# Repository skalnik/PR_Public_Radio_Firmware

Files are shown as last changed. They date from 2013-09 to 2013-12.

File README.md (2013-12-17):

PR_Public_Radio README
===============
Created 2013.12.17
by Spencer Wright
===============
SYNOPSIS
The Public Radio is a project which spans industrial design, embedded systems design, and firmware.The files located within this project comprise a subset of the data reqired to fully complete ThePublic Radio, though efforts are being made to completely describe the project from top to bottom.
===============
CREDITS
The work herein is primarily a collaboration between Spencer Wright (http://pencerw.com) and Zach Dunham (http://zachdunham.com) though much ofit was adapted heavily from friendly sources. In particular, early versions of the firmware was adapted directly from Nathan Seidle et al (Sparkfun). Special thanks also goes to Todd Bailey (http://blog.narrat1ve.com/).
===============
LICENSE
In the interest of collaboration and good will, the files herein are offered for public use. Just don't be a jerk about it, etc., and do let us know if we've screwed something really big up (and, of course, we certainly have :).
At some point in the future, The Public Radio will be made commercially available. Inasmuch as it is feasible, we hope to continue to keep the design files and firmware here available for noncommercial use.
===============
PROJECT DESCRIPTION
The Public Radio is a single channel, single speaker FM receiver. 
As a piece of hardware, it was intended to be as simple as possible. One midrange speaker mounted inside a simple enclosure, with a single switched knob which controls power and adjusts volume.
Early on in the project, we planned on building a custom aluminum enclosure, but decided to protoype using an off-the-shelf container - a Ball brand mason jar. The enclosure requires one custom manufactured part: a replacement lid, to which the speaker, potentiometer, and electronics mount.
As I write this, the electronics consist primarily of off-the-shelf components: Arduino Pro Mini, Sparkfun breakout & evaluation boards. Our plan for the next few months includes stripping the hardware down to its barest components and discarding the prototyping tools we've used to get ourselves off the ground.
The firmware required to run The Public Radio is simple. The main Arduino sketch does the following:
  Defines three output pins
  Defines "channel" (FM frequency) and "volume" variables
  Instantiates the class Public_Radio
  Enables the Si4703 FM receiver chip
  Tunes to the defined frequency 
  Sets the volume
Also included are stripped down versions of the Si4703 written by Sparkfun and available at https://github.com/sparkfun/Si4703_FM_Tuner_Evaluation_Board. As my understanding of these is limited, I'll reserve description until a later date.
===============
CONTAINED HEREIN
  Industrial design files: These are mostly outdated, and were created in SolidWorks. Current versions, created primarily in Autodesk Inventor, still need to be folded into this repo.
  Embedded systems design files: Namely .brd, .sch, possibly gerbers. These will remain up-to-date, so long as I can keep ZD on his game :)
  Firmware: Arduino sketches, library files (header & source). 
===============
ELSE
I'm new to this game. Holler at me if I'm missing something.

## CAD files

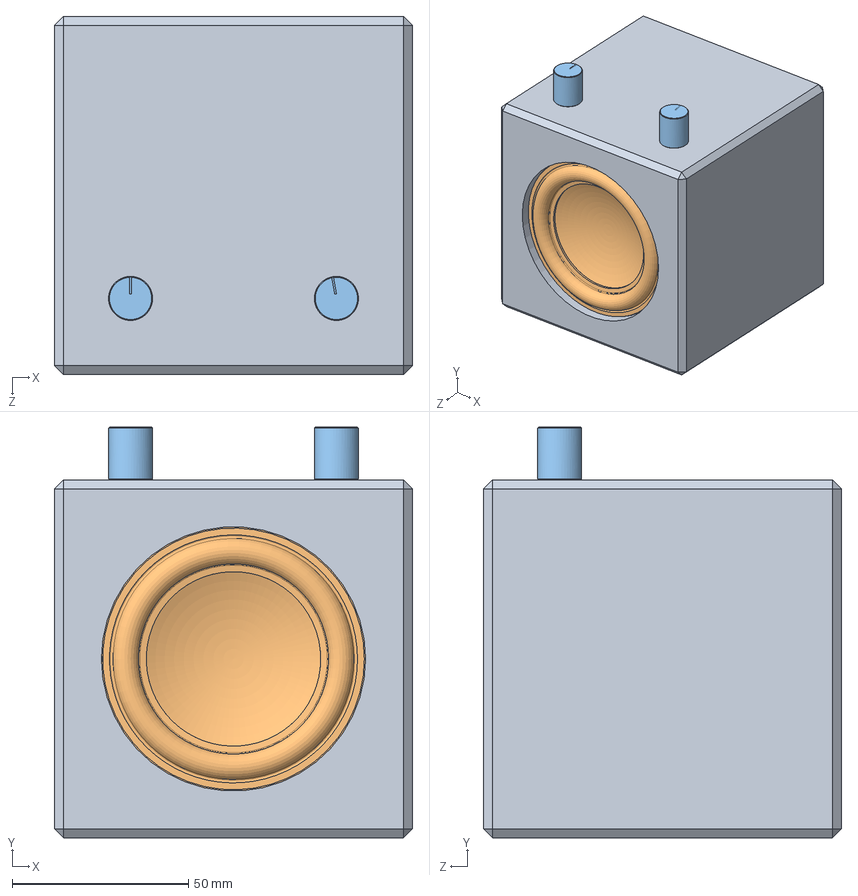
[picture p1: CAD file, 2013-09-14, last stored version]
APR1001 Public Radio.SLDASM
101.6 x 116.6 x 101.6 mm
PR1001 Speaker box
PR2001 Speaker Swan B3S
PR1002 Knob x 2

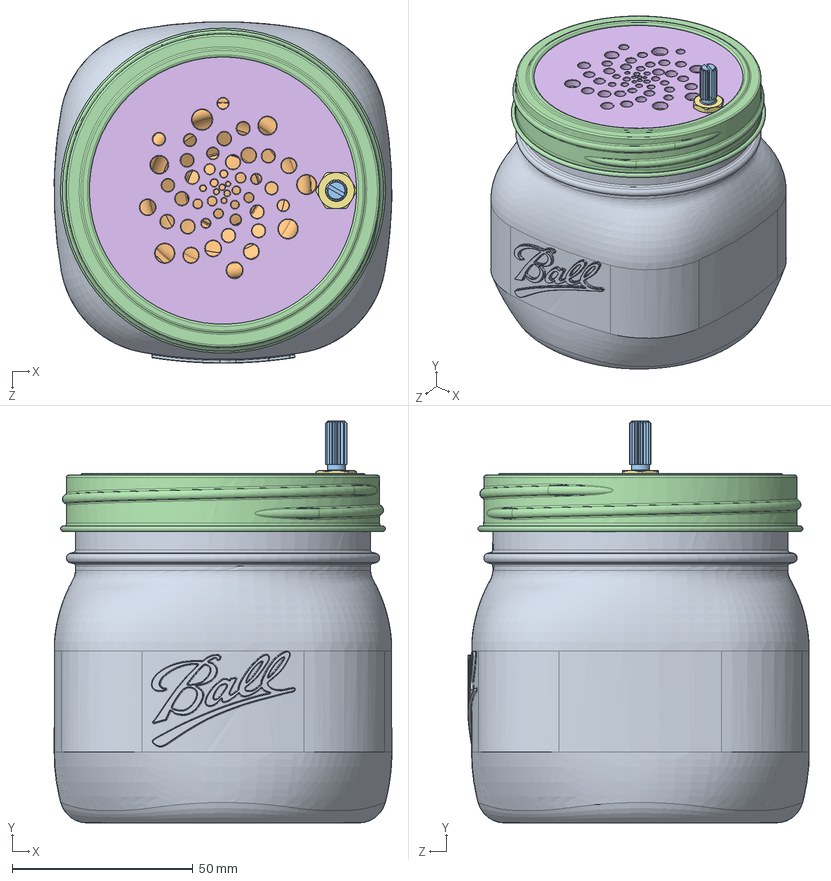
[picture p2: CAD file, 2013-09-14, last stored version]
PR_Solidworks/APR1002 Ball Public Radio.SLDASM
93.4 x 111.2 x 94.5 mm
PR2003 Ball Jar 500mL squareish
PR2004 Speaker Viifa TC6FC00-04
PR2005 Potentiometer Bourns BTR901-2015K-A103
PR2006 Ball Wide Mouth Ring
PR2007 9 Volt Battery
PR1005 Fibonacci Lid 2
PR2008 Bourns locknut

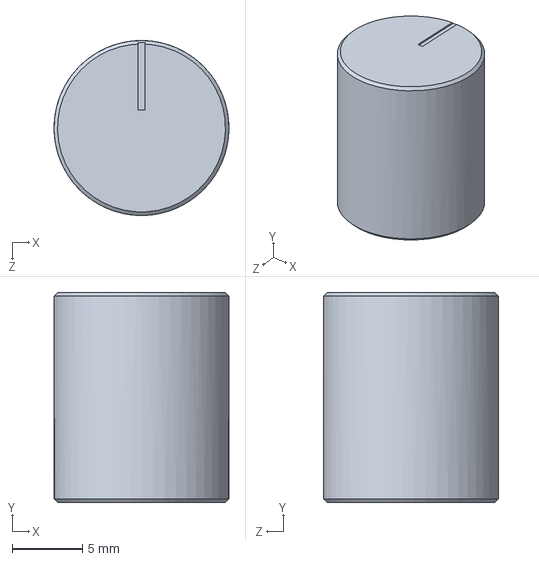
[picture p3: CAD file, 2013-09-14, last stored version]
PR1002 Knob.SLDPRT
12.5 x 15.0 x 12.5 mm

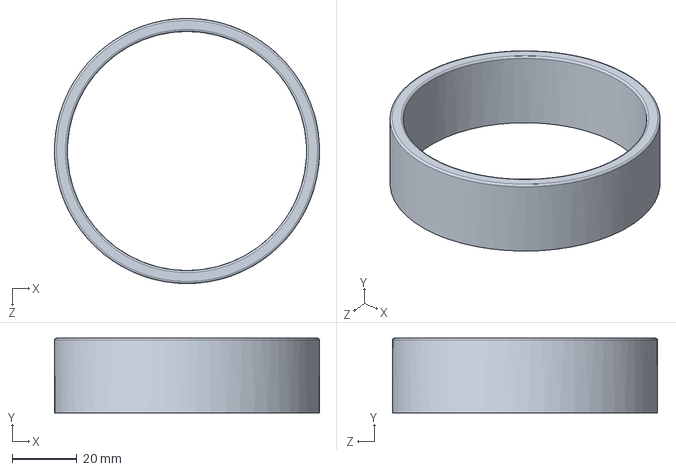
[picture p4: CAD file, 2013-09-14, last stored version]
PR_Solidworks/PR2003 Ball Jar 1qt squareish.SLDPRT
81.8 x 23.1 x 81.8 mm

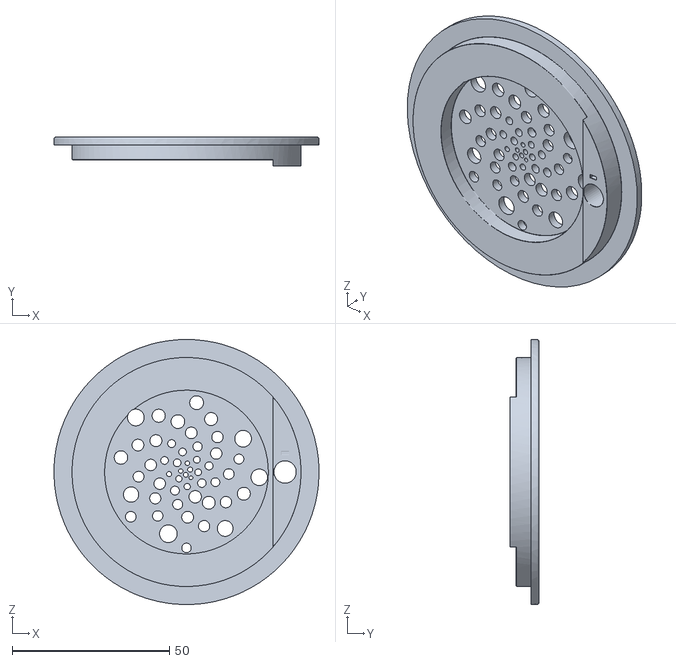
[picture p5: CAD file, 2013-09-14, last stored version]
PR_Solidworks/Static Exports/PR1005 Fibonacci Lid 2.STL
84.3 x 9.30 x 84.3

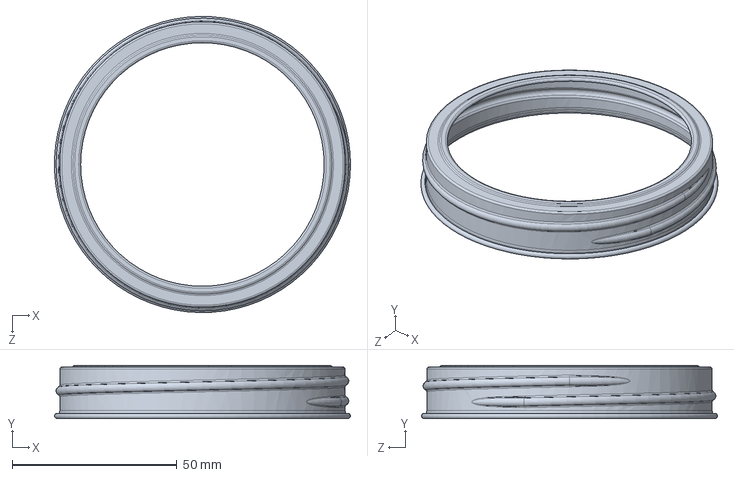
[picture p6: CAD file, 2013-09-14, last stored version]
PR_Solidworks/PR2006 Ball Wide Mouth Ring.SLDPRT
89.9 x 16.1 x 89.9 mm

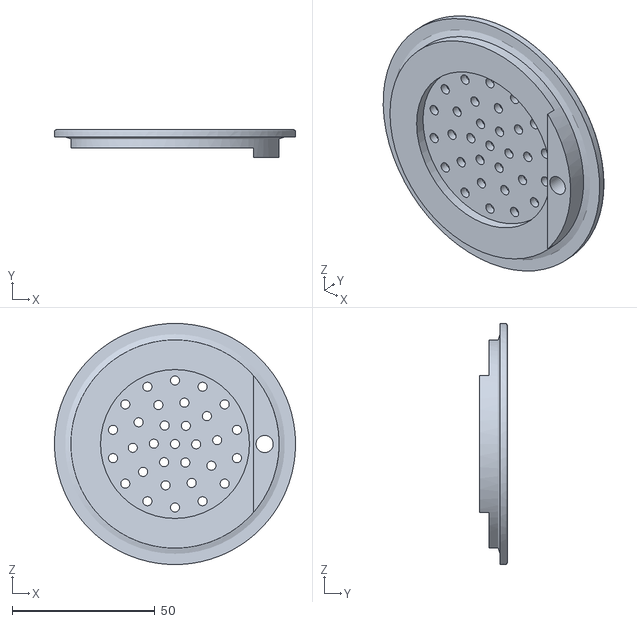
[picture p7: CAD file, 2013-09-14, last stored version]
PR_Solidworks/Static Exports/PR1003 Lid.STL
84.3 x 9.65 x 84.3

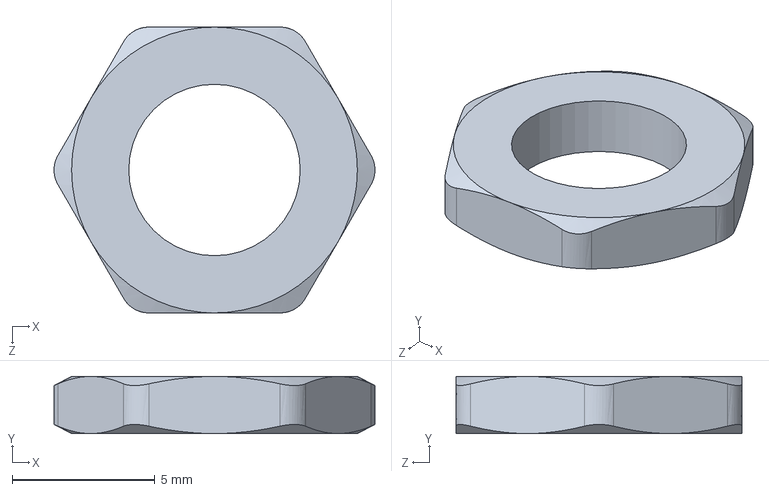
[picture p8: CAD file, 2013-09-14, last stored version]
PR2008 Bourns locknut.SLDPRT
11.2 x 2.00 x 10.0 mm

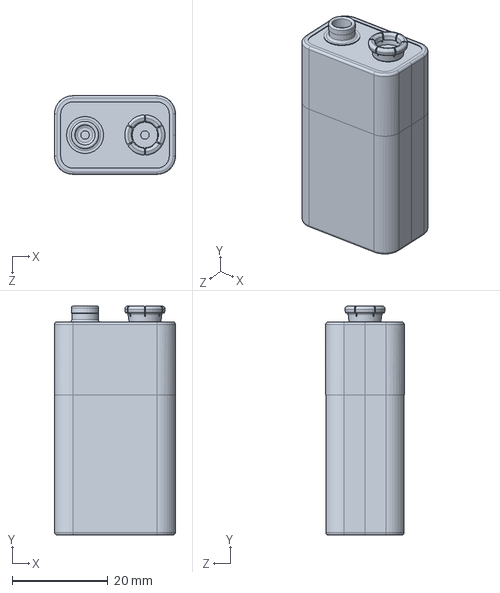
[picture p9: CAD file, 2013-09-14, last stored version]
PR_Solidworks/PR2007 9 Volt Battery.SLDPRT
25.2 x 47.8 x 16.4 mm

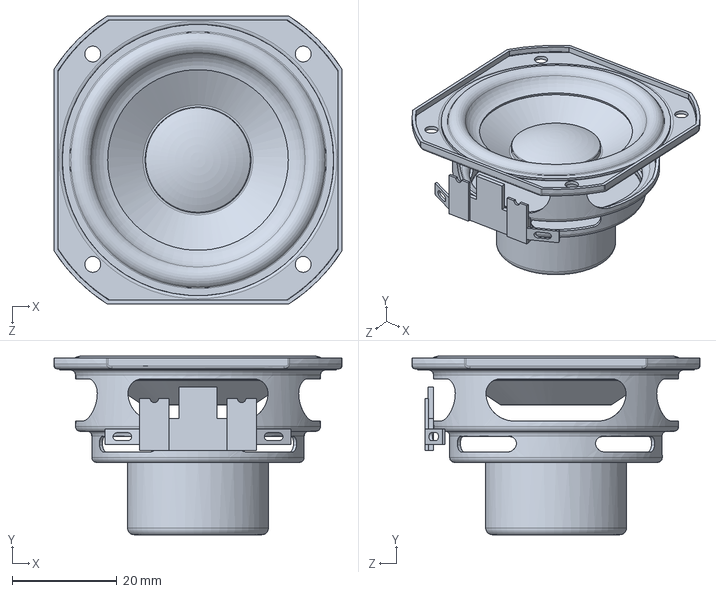
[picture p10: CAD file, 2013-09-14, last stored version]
PR_Solidworks/PR2004 Speaker Viifa TC6FC00-04.SLDPRT
54.9 x 34.0 x 54.9 mm

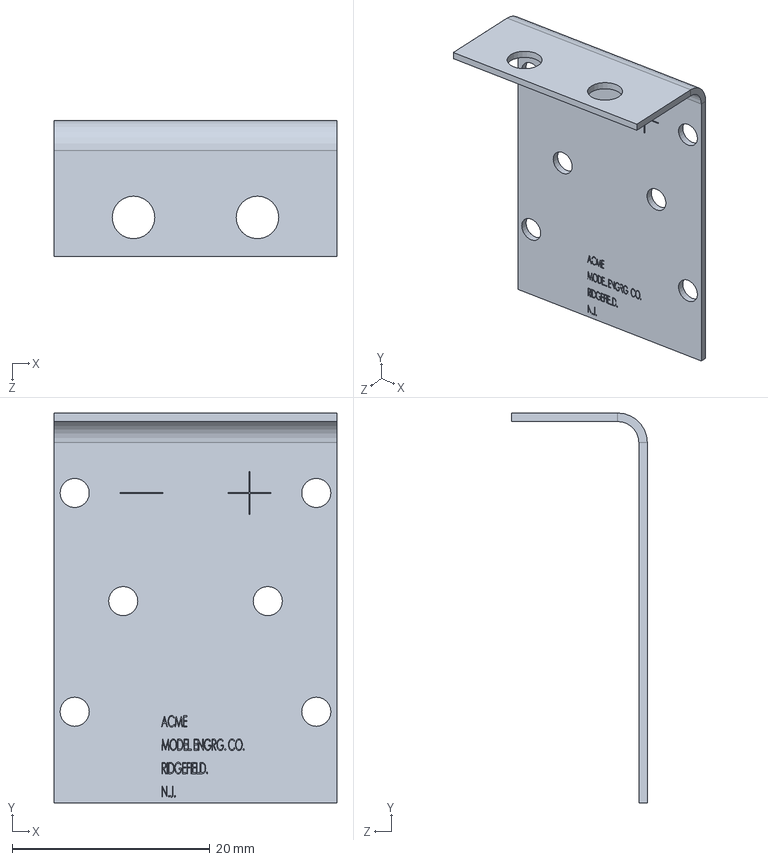
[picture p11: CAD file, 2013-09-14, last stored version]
PR_Solidworks/PR2002A Acme 9v holder base.SLDPRT
28.6 x 39.4 x 13.7 mm

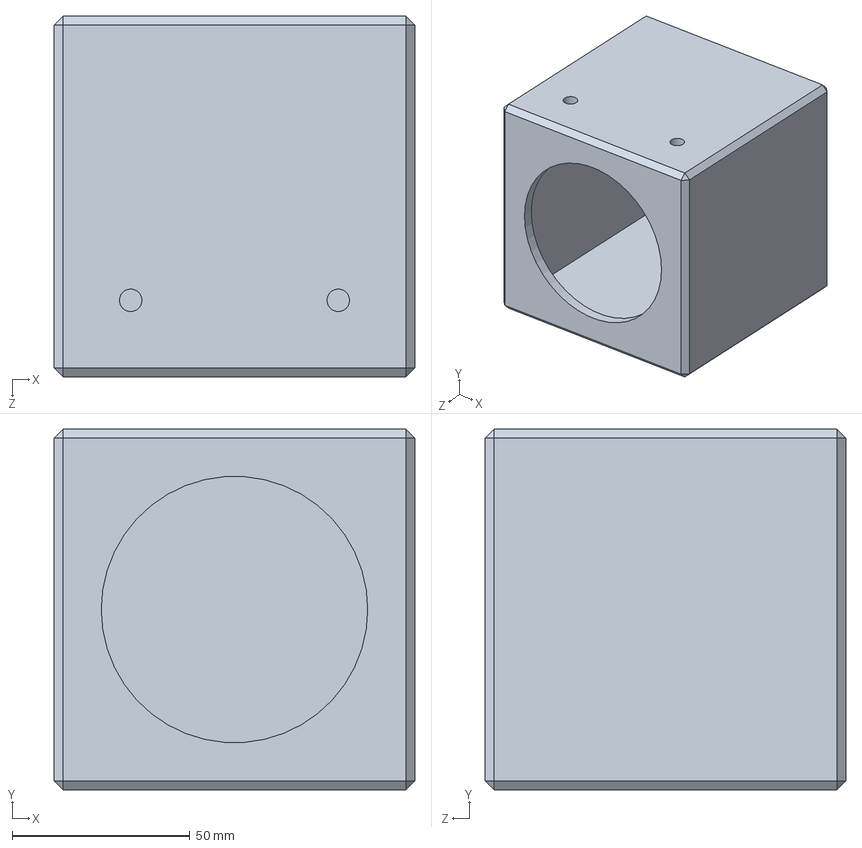
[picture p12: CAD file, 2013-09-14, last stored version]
PR1001 Speaker box.SLDPRT
101.6 x 101.6 x 101.6 mm

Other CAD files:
PR_Solidworks/Static Exports/PR1005 Fibonacci Lid 2 REV-A.STL
PR1003 Lid.SLDPRT
PR1004 Fibonacci Lid.SLDPRT
PR1005 Fibonacci Lid 2.SLDPRT
PR2001 Speaker Swan B3S.SLDPRT
PR2005 Potentiometer Bourns BTR901-2015K-A103.SLDPRT
PR_Solidworks/PR1003 Lid.SLDPRT
PR_Solidworks/PR1004 Fibonacci Lid.SLDPRT
PR_Solidworks/PR1005 Fibonacci Lid 2.SLDPRT
PR_Solidworks/PR2001 Speaker Swan B3S.SLDPRT
PR_Solidworks/PR2005 Potentiometer Bourns BTR901-2015K-A103.SLDPRT
Static Exports/PR1005 Fibonacci Lid 2 REV-A.STL

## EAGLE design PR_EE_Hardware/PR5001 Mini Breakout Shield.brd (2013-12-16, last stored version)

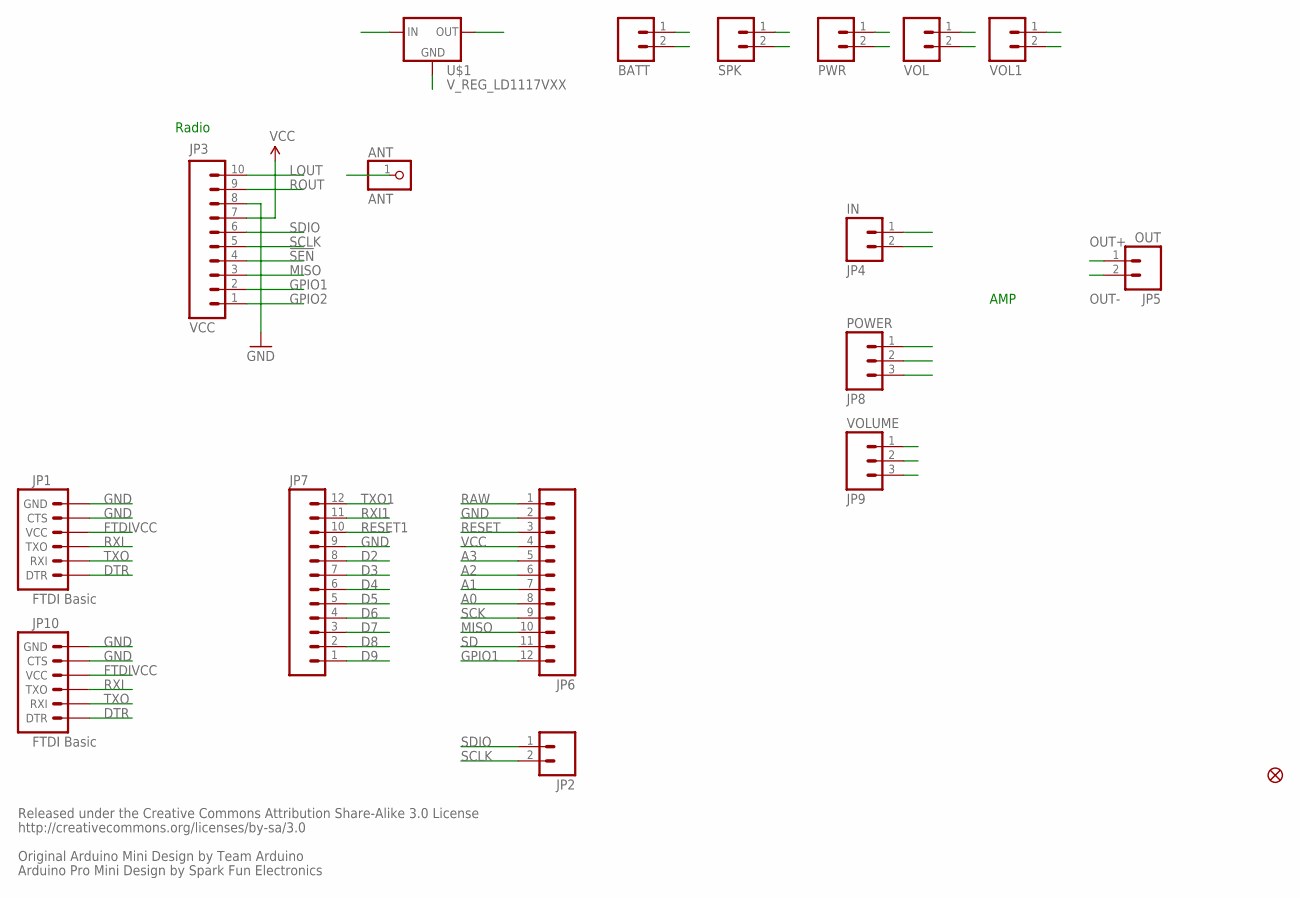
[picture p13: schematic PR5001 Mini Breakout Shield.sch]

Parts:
ANT: ANT; 1X01
BATT: M02PTH; 1X02
JP1, JP10: FTDI Basic; 1X06
JP2: M02PTH; 1X02
JP3: VCC; 1X10
JP4: IN; 1X02
JP5: OUT; 1X02
JP6, JP7: M12PTH; 1X12
JP8: POWER; 1X03
JP9: VOLUME; 1X03
PWR: M02PTH; 1X02
SPK: M02PTH; 1X02
U$1: V_REG_LD1117VXX; 78XXL
U$4: FIDUCIAL1X2; FIDUCIAL-1X2
VOL, VOL1: M02PTH; 1X02

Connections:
!SEN: JP3.4
A0: JP6.8
A1: JP6.7
A2: JP6.6
A3: JP6.5
ANT: ANT.1, VOL1.2
BATT+: BATT.1, PWR.1
D2: JP7.8
D3: JP7.7
D4: JP7.6
D5: JP7.5
D6: JP7.4
D7: JP7.3
D8: JP7.2
D9: JP7.1
DTR: JP1.1 (DTR), JP10.1 (DTR)
FTDIVCC: JP1.4 (VCC), JP10.4 (VCC)
GND: BATT.2, JP1.5 (CTS), JP1.6 (GND), JP3.8, JP4.2, JP6.2, JP7.9, JP8.1, JP9.1, JP10.5 (CTS), JP10.6 (GND), U$1.IN (GND), VOL.1
GPIO1: JP3.2, JP6.12
GPIO2: JP3.1
IN: JP9.3, VOL1.1
LOUT: JP3.10, JP4.1
MISO: JP3.3, JP6.10
OPUT: JP9.2, VOL.2
OUT+: JP5.1, SPK.1
OUT-: JP5.2, SPK.2
POT+: PWR.2, U$1.OUT (IN)
RAW: JP6.1
RESET: JP6.3
RESET1: JP7.10
ROUT: JP3.9
RXI: JP1.3 (TXO), JP10.3 (TXO)
RXI1: JP7.11
SCK: JP6.9
SCLK: JP2.2, JP3.5
SD: JP6.11, JP8.3
SDIO: JP2.1, JP3.6
TXO: JP1.2 (RXI), JP10.2 (RXI)
TXO1: JP7.12
VCC: JP3.7, JP6.4, JP8.2, U$1.GND (OUT)

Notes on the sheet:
Released under the Creative Commons Attribution Share-Alike 3.0 License
http://creativecommons.org/licenses/by-sa/3.0
Original Arduino Mini Design by Team Arduino
Arduino Pro Mini Design by Spark Fun Electronics
AMP
Radio

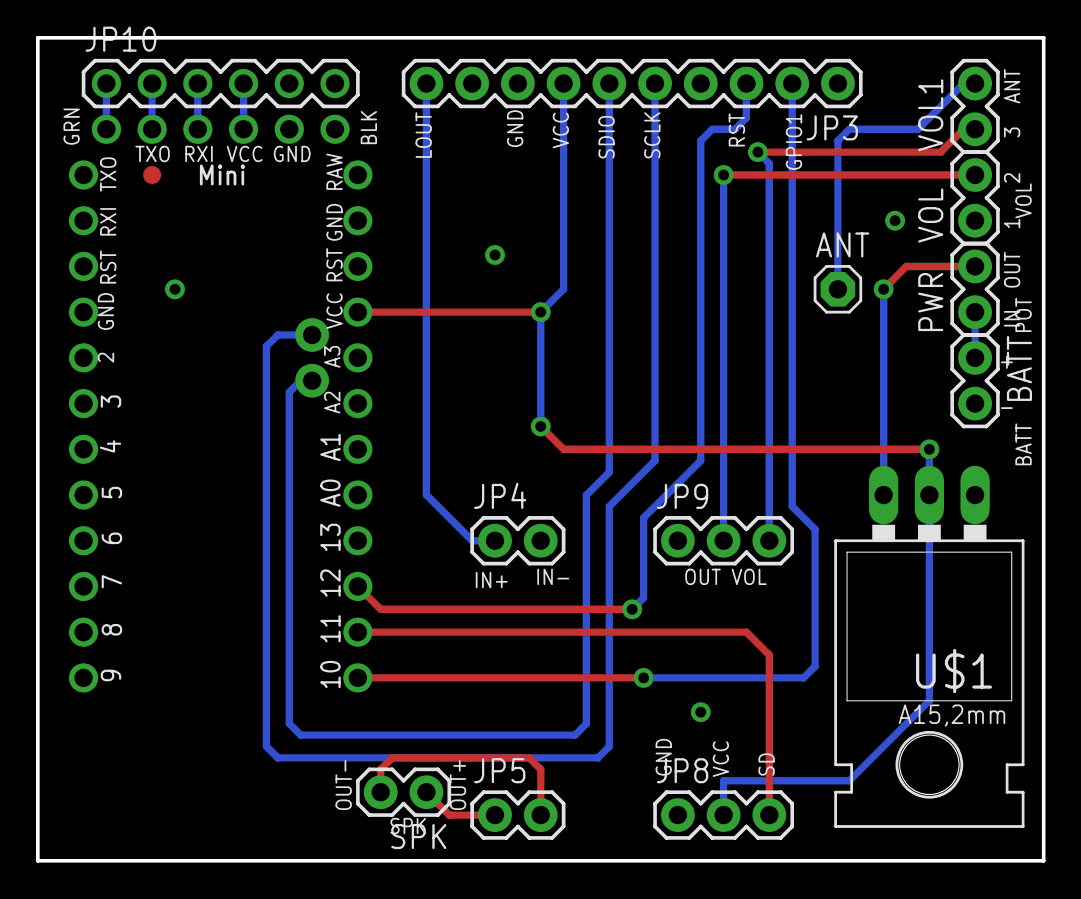
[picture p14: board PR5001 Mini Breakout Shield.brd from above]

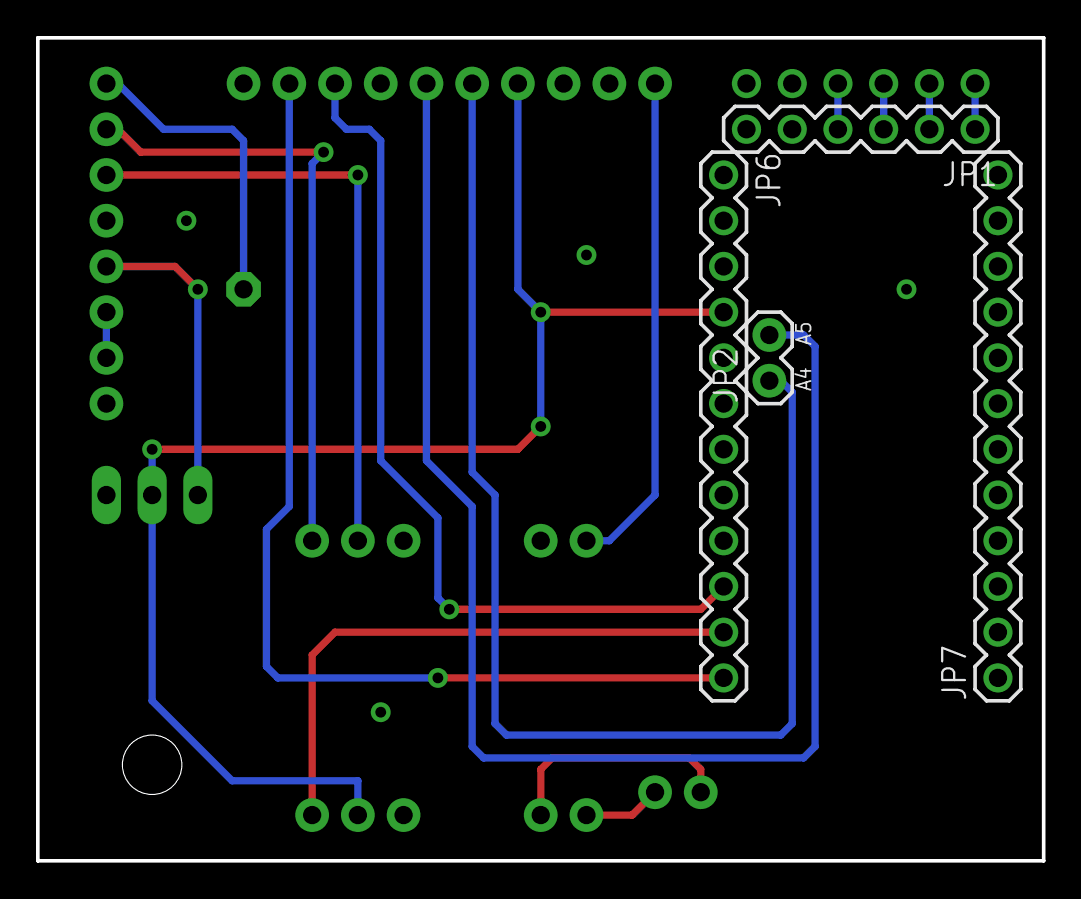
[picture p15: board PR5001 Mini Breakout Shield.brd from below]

Board: 2 copper layers, 55.9 x 45.7 mm, 18 parts (4 on the bottom side), 19 nets.

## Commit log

2013-09-14 posting for the first time
    [APR1001 Public Radio.SLDASM, APR1002 Ball Public Radio.SLDASM, PR1001 Speaker box.SLDPRT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]
2013-12-16 moved solid files to their own directory
    [APR1001 Public Radio.SLDASM, APR1002 Ball Public Radio.SLDASM, PR1001 Speaker box.SLDPRT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]
2013-12-16 Added EE stuff from ZD, added libraries
    [PR5001 Mini Breakout Shield.brd, PR5001 Mini Breakout Shield.sch]
2013-12-17 rolling back, basically
    aliases basically don’t work for shit.
2013-12-17 breaking everything up
    keeping multiple local directories linked to one GitHub repo is too
    much for me right now. breaking it up into multiple parts - this one
    will be firmware ONLY.
    [APR1001 Public Radio.SLDASM, APR1002 Ball Public Radio.SLDASM, PR1001 Speaker box.SLDPRT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]

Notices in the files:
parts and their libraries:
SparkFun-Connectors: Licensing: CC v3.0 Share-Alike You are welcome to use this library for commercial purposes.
